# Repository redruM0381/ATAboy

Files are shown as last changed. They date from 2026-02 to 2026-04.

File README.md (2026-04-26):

If you don't want to build your own, the hardware can be purchased here:  https://obsoletetech.us/products/ataboy-an-open-source-legacy-ide-usb-bridge

-----------------------------------------------------------------------------------

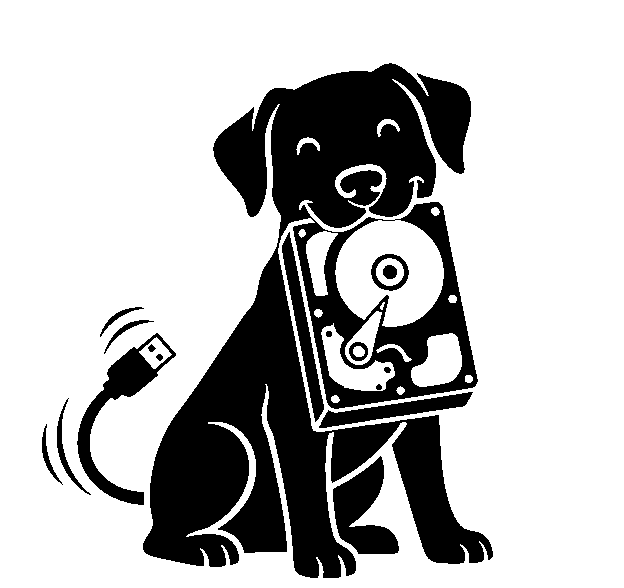
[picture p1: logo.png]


ATAboy is designed for retro computing enthusiasts, data recovery experts, and archivists.  Read and write the oldest of IDE hard drives, without the need for an "in-between" vintage computer!

ATAboy is a user-friendly bridge that allows classic IDE (PATA) hard drives to be connected to a modern computer over USB as a standard USB Mass Storage device.  While cheap, modern adapters usually only work with newer "LBA" type drives, ATAboy works all the way back to the earliest CHS only, PIO Mode 0, ATA disks.  (It will also work with newer LBA type IDE disks, but that's not really what it's designed for.)  ATAboy features an "Award BIOS inspired" user friendly UI for drive configuration and setup.

---

When connected:

* The IDE drive appears to your computer like a normal USB Mass Storage Device
* No special drivers are required (Windows, Linux, macOS supported)
* The device translates USB Mass Storage commands into IDE read/write operations

---

## Hardware Requirements

To get started, you will also need:

* Any 40‑pin IDE (PATA) hard drive. It may be jumpered master, slave, or cable select.
* An external PSU to power the drive.
* A USB-C cable to connect ATAboy to the host computer.
* Any standard ANSI compatible serial terminal emulator (e.g. PuTTY, Tera Term, minicom, screen, etc.)

---

## Basic drive mount using ATABoy

1. Connect the IDE ribbon cable to the drive and ATAboy (Note Pin 1 orientation, usually marked by a stripe on the cable)
2. Power the drive using external supply
3. Connect ATAboy to your computer via USB
4. Connect to serial console with terminal of choice ([PuTTY](https://www.chiark.greenend.org.uk/~sgtatham/putty/latest.html) shown).  9600 8N1, no flow control.  You should see an Award BIOS "inspired" text-based UI appear in the terminal.
5. Enter the "Auto Detect & Set Geometry" menu
6. Choose default, or enter geometry manually if needed
7. Choose "Mount HDD to USB Mass Storage"
8. That's it!  You can now read the drive from your modern OS!

---

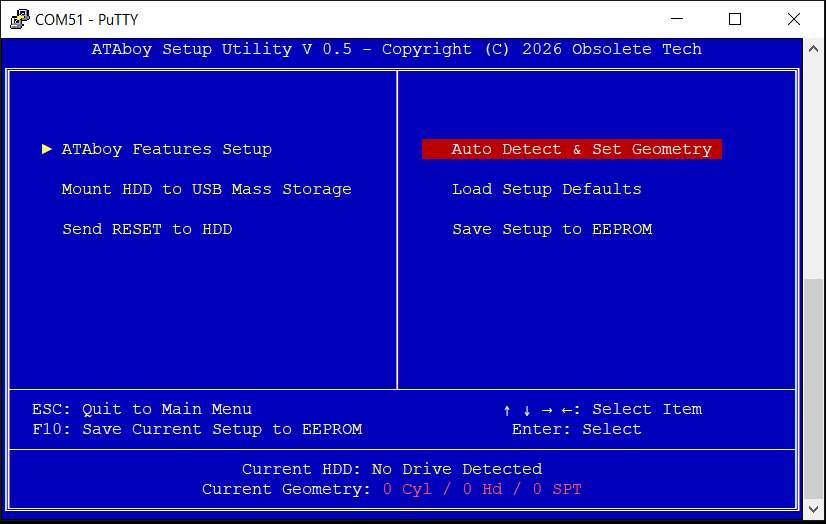
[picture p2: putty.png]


You can save the current ATAboy settings, geometry, etc to EEPROM, which will be restored the next time the device is booted.  (This allows auto-mounting also.)

IMPORTANT!  If you are working with valuable or irreplaceable data, ensure write protection is enabled before mounting.  It is enabled by default for safety.  You do NOT want the host OS to touch or bless the disk!
Windows VDS/RPC services can often crash if it is unable to write to a drive with damaged/legacy MBR and/or partition tables.
This can result in various Windows errors, unable to mount the drive, etc.  However, raw data can usually still be accessed via dd, or other raw disk backup software.
Regardless, it is STRONGLY recommended the entire drive be dumped to an image file BEFORE disabling write protection, then mounting the drive in Explorer.

---

## Safe Removal

Always use your operating system’s **Safely Remove / Eject** feature before:

* Unplugging the USB cable
* Powering off the IDE drive

This helps prevent:

* File system corruption
* Incomplete writes
* OS-side errors

---

## Known Limitations

ATAboy is a hobbyist and experimental project. You should be aware that:

* Performance is significantly slower than modern USB to IDE bridges.  We're working over USB 1.1 for now.  This can cause long mount times, especially in Windows if the disk has file system weirdness.
* Many legacy disks use unusual geometry, and may require experimentation.
* Not all OS disk utilities behave the same way

# PLEASE NOTE!
Some of the firmware code was written with AI assistance.  It has been tested with dozens of drives, and does function well with most.  But may be buggy, slow, or unresponsive with certain drives. Please let us know if you find a drive that does or doesn't work right. We'll build a compatibilty list soon.
# Use at your own risk!

* Firmware written in VS Code with Raspberry Pi Pico Extension
* PCB designed in Kicad
* Case designed in Freecad

---

ATAboy is meant to be hacked, learned from, and improved.
Have fun, and thank you for trying ATAboy!

# Licensing

"ATAboy" is a trademark of JJ Dasher.
The open source licenses do not grant rights to use these trademarks.

## Firmware
Licensed under GNU GPLv3.
See /firmware/LICENSE.

## Hardware
Licensed under CERN-OHL-W v2.
See /PCB/LICENSE.

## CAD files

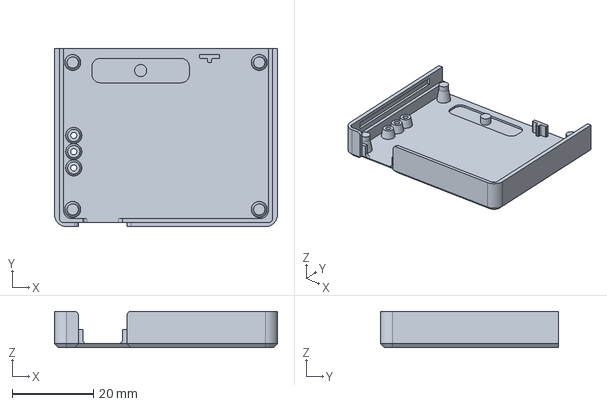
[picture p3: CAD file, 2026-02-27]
Case STLs/case_angled_shroud.FCStd
55.0 x 44.0 x 9.00 mm

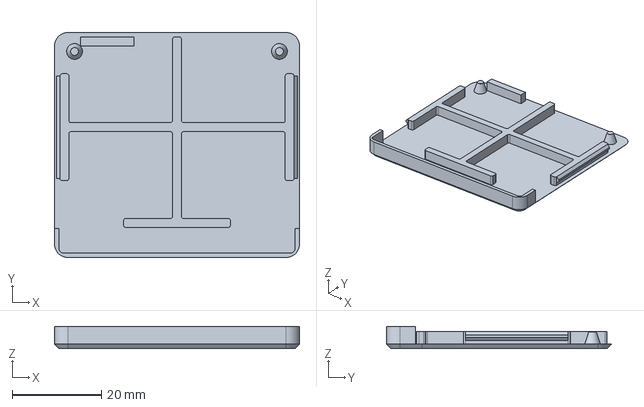
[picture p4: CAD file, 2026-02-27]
Case STLs/lid_angled_shroud.FCStd
55.0 x 50.5 x 5.00 mm

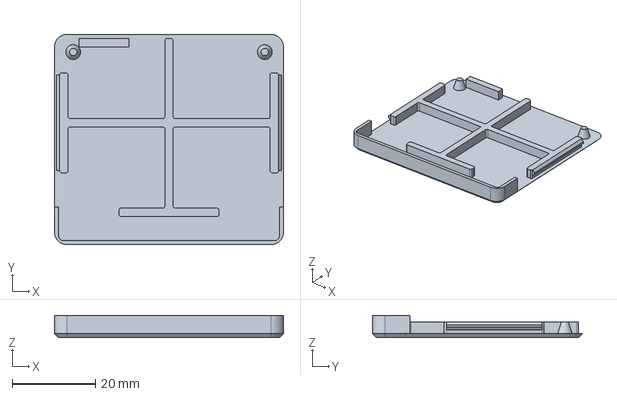
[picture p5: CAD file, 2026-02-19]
Case STLs/lid_vert_shroud.FCStd
55.0 x 50.5 x 5.40 mm

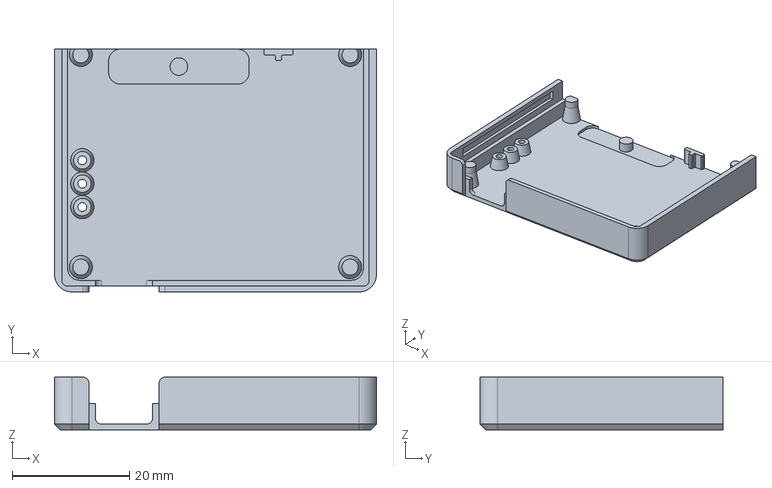
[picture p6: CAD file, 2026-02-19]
Case STLs/case_vert_shroud.FCStd
55.0 x 41.5 x 9.00 mm

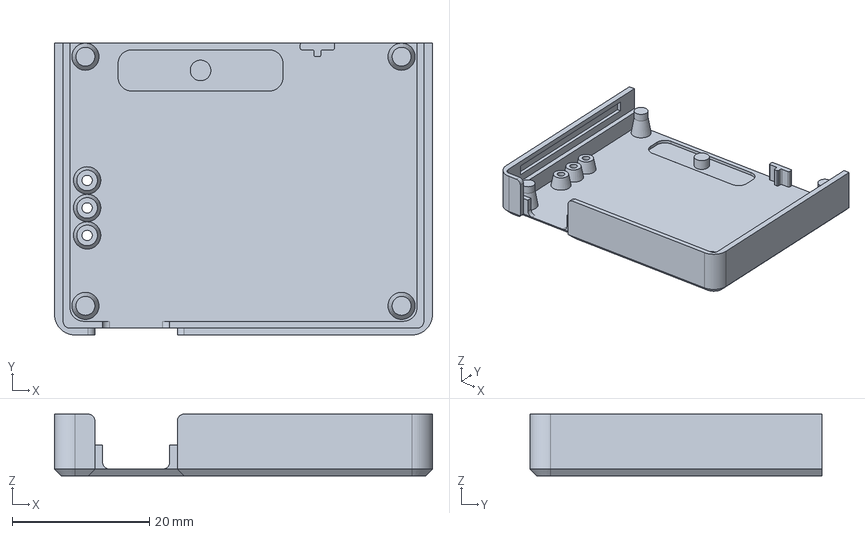
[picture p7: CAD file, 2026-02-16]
Case STLs/case_vert_header.FCStd
55.0 x 42.5 x 9.00 mm

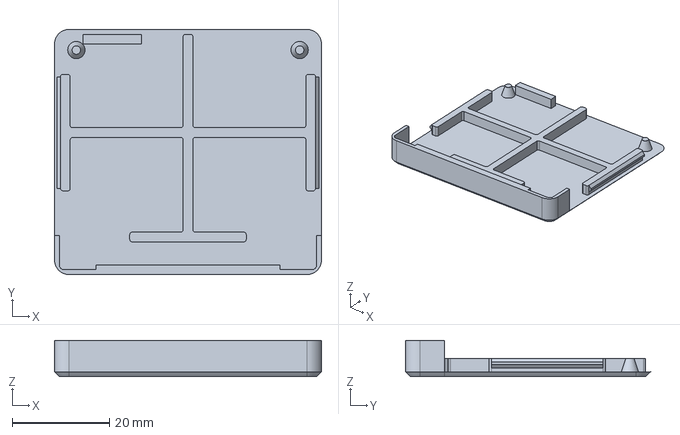
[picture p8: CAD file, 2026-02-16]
Case STLs/lid_vert_header.FCStd
55.0 x 50.5 x 7.50 mm

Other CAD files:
Case STLs/case_angled_shroud.stl
Case STLs/case_vert_header.stl
Case STLs/case_vert_shroud.stl
Case STLs/lid_angled_shroud.stl
Case STLs/lid_vert_header.stl
Case STLs/lid_vert_shroud.stl

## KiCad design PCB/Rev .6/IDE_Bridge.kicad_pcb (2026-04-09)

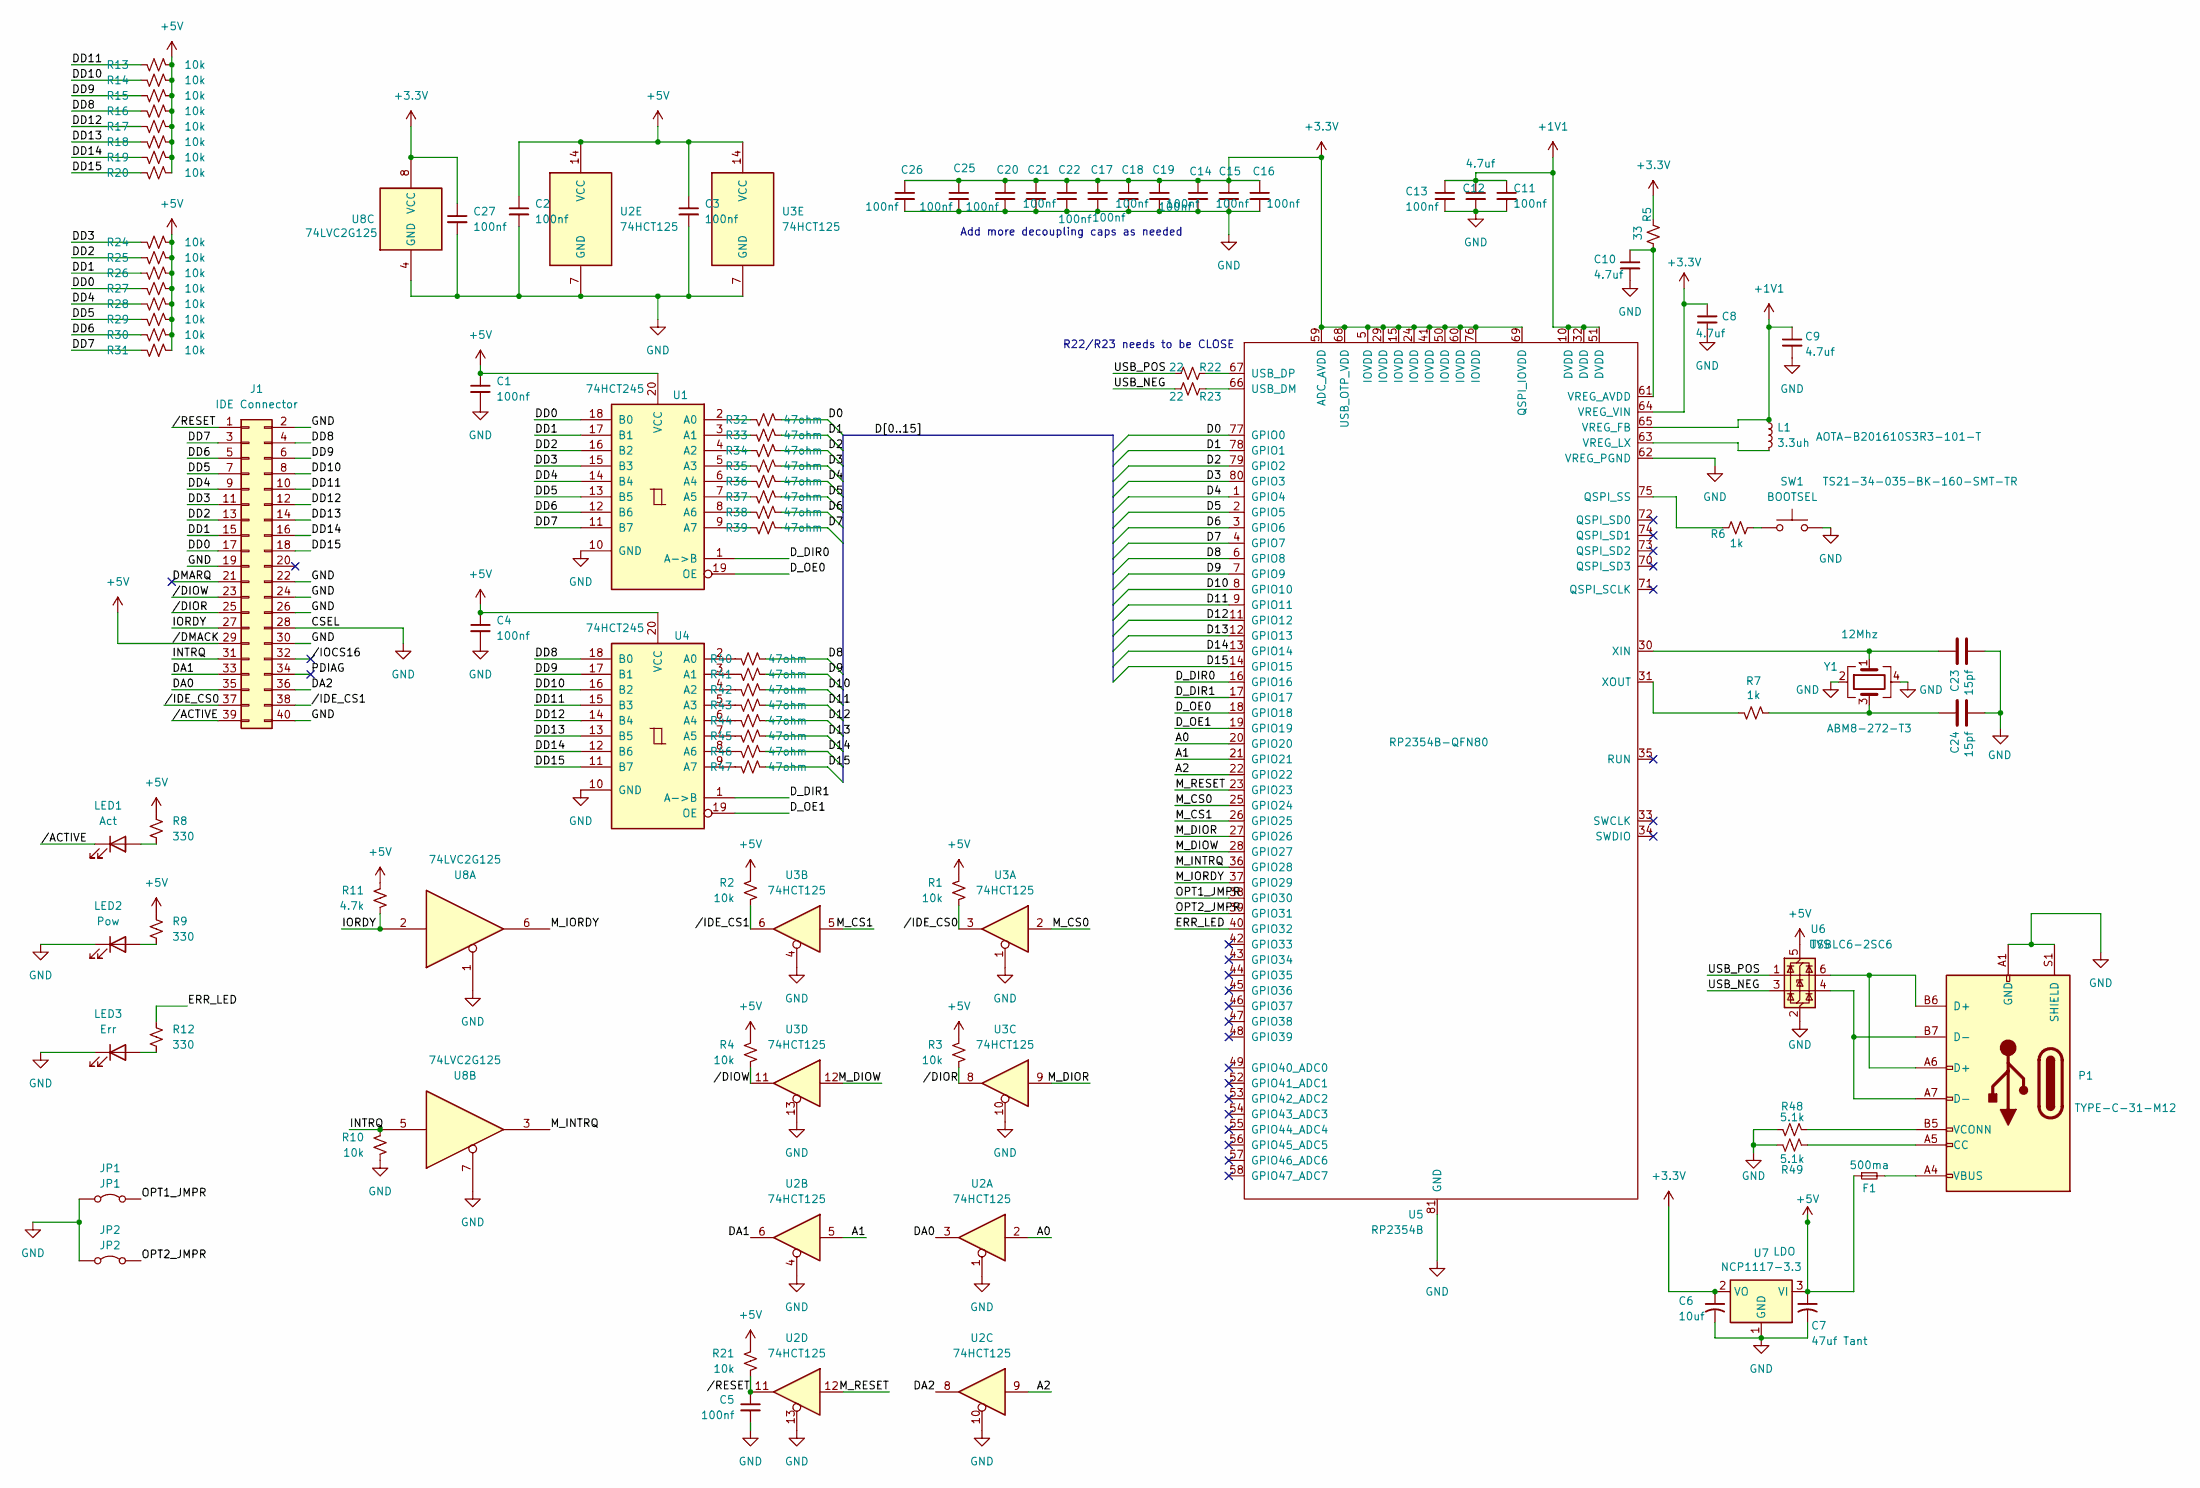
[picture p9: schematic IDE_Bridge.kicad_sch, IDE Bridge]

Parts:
C1, C2, C3, C4, C5, C11, C13, C14, C15, C16, C17, C18, C19, C20, C21, C22, C25, C26, C27: 100nf; C_0402_1005Metric; LCSC C1525
C6: 10uf; C_1206_3216Metric; LCSC C13585
C7: 47uf Tant; CP_EIA-6032-28_Kemet-C; LCSC C7219
C8, C9, C10, C12: 4.7uf; C_0402_1005Metric; LCSC C23733
C23, C24: 15pf; C_0402_1005Metric; LCSC C1548
F1: 500ma; Fuse_0805_2012Metric; LCSC C22435710
J1: IDE Connector; PinHeader_2x20_P2.54mm_Horizontal
JP1: JP1; PinHeader_1x02_P2.54mm_Vertical
JP2: JP2; PinHeader_1x02_P2.54mm_Vertical
L1: 3.3uh; L_Murata_DFE201610P; LCSC C42411119
LED1: Act; LED_0805_2012Metric; LCSC C2296
LED2: Pow; LED_0805_2012Metric; LCSC C2297
LED3: Err; LED_0805_2012Metric; LCSC C84256
P1: USB_C_Plug_USB2.0; USB_C_Receptacle_HRO_TYPE-C-31-M-12; LCSC C165948
R1, R2, R3, R4, R10, R13, R14, R15, R16, R17, R18, R19, R20, R21, R24, R25, R26, R27, R28, R29, R30, R31: 10k; R_0402_1005Metric; LCSC C25744
R5: 33; R_0402_1005Metric; LCSC C25105
R6, R7: 1k; R_0402_1005Metric; LCSC C11702
R8, R9, R12: 330; R_0402_1005Metric; LCSC C25104
R11: 4.7k; R_0402_1005Metric; LCSC C25900
R22, R23: 22; R_0402_1005Metric; LCSC C25092
R32, R33, R34, R35, R36, R37, R38, R39, R40, R41, R42, R43, R44, R45, R46, R47: 47ohm; R_0402_1005Metric; LCSC C25118
R48, R49: 5.1k; R_0402_1005Metric; LCSC C25905
SW1: BOOTSEL; SW_SPST_SKQG_WithStem; LCSC C318884
U1, U4: 74HCT245; SOIC-20W_7.5x12.8mm_P1.27mm; LCSC C5625
U2, U3: 74HCT125; SOIC-14_3.9x8.7mm_P1.27mm; LCSC C352957
U5: RP2354B; RP2350B; LCSC C39843328
U6: TVS; SOT-23-6; LCSC C2687116
U7: LDO; SOT-223-3_TabPin2; LCSC C6186
U8: 74LVC2G125; VSSOP-8_3x3mm_P0.65mm; LCSC C206035
Y1: 12Mhz; Crystal_SMD_3225-4Pin_3.2x2.5mm; LCSC C20625731

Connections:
+1V1: C9.1, C11.1, C12.1, C13.1, L1.1, U5.10 (DVDD), U5.32 (DVDD), U5.51 (DVDD), U5.65 (VREG_FB)
+3.3V: C6.1, C8.1, C14.1, C15.1, C16.1, C17.1, C18.1, C19.1, C20.1, C21.1, C22.1, C25.1, C26.1, C27.1, R5.2, U5.5 (IOVDD), U5.15 (IOVDD), U5.24 (IOVDD), U5.29 (IOVDD), U5.41 (IOVDD), U5.50 (IOVDD), U5.59 (ADC_AVDD), U5.60 (IOVDD), U5.64 (VREG_VIN), U5.68 (USB_OTP_VDD), U5.69 (QSPI_IOVDD), U5.76 (IOVDD), U7.2 (VO), U8.8 (VCC)
+5V: C1.1, C2.1, C3.1, C4.1, C7.1, F1.1, J1.29, R1.1, R2.1, R3.1, R4.1, R8.1, R9.1, R11.1, R13.2, R14.2, R15.2, R16.2, R17.2, R18.2, R19.2, R20.2, R21.1, R24.2, R25.2, R26.2, R27.2, R28.2, R29.2, R30.2, R31.2, U1.20 (VCC), U2.14 (VCC), U3.14 (VCC), U4.20 (VCC), U6.5 (VBUS), U7.3 (VI)
/A0: U2.2, U5.20 (GPIO20)
/A1: U2.5, U5.21 (GPIO21)
/A2: U2.9, U5.22 (GPIO22)
/D0: R32.2, U5.77 (GPIO0)
/D1: R33.2, U5.78 (GPIO1)
/D2: R34.2, U5.79 (GPIO2)
/D3: R35.2, U5.80 (GPIO3)
/D4: R36.2, U5.1 (GPIO4)
/D5: R37.2, U5.2 (GPIO5)
/D6: R38.2, U5.3 (GPIO6)
/D7: R39.2, U5.4 (GPIO7)
/D8: R40.2, U5.6 (GPIO8)
/D9: R41.2, U5.7 (GPIO9)
/D10: R42.2, U5.8 (GPIO10)
/D11: R43.2, U5.9 (GPIO11)
/D12: R44.2, U5.11 (GPIO12)
/D13: R45.2, U5.12 (GPIO13)
/D14: R46.2, U5.13 (GPIO14)
/D15: R47.2, U5.14 (GPIO15)
/DA0: J1.35, U2.3
/DA1: J1.33, U2.6
/DA2: J1.36, U2.8
/DD0: J1.17, R27.1, U1.18 (B0)
/DD1: J1.15, R26.1, U1.17 (B1)
/DD2: J1.13, R25.1, U1.16 (B2)
/DD3: J1.11, R24.1, U1.15 (B3)
/DD4: J1.9, R28.1, U1.14 (B4)
/DD5: J1.7, R29.1, U1.13 (B5)
/DD6: J1.5, R30.1, U1.12 (B6)
/DD7: J1.3, R31.1, U1.11 (B7)
/DD8: J1.4, R16.1, U4.18 (B0)
/DD9: J1.6, R15.1, U4.17 (B1)
/DD10: J1.8, R14.1, U4.16 (B2)
/DD11: J1.10, R13.1, U4.15 (B3)
/DD12: J1.12, R17.1, U4.14 (B4)
/DD13: J1.14, R18.1, U4.13 (B5)
/DD14: J1.16, R19.1, U4.12 (B6)
/DD15: J1.18, R20.1, U4.11 (B7)
/DMARQ: J1.21
/D_DIR0: U1.1 (A->B), U5.16 (GPIO16)
/D_DIR1: U4.1 (A->B), U5.17 (GPIO17)
/D_OE0: U1.19 (OE), U5.18 (GPIO18)
/D_OE1: U4.19 (OE), U5.19 (GPIO19)
/ERR_LED: R12.1, U5.40 (GPIO32)
/INTRQ: J1.31, R10.1, U8.5
/IORDY: J1.27, R11.2, U8.2
/M_CS0: U3.2, U5.25 (GPIO24)
/M_CS1: U3.5, U5.26 (GPIO25)
/M_DIOR: U3.9, U5.27 (GPIO26)
/M_DIOW: U3.12, U5.28 (GPIO27)
/M_INTRQ: U5.36 (GPIO28), U8.3
/M_IORDY: U5.37 (GPIO29), U8.6
/M_RESET: U2.12, U5.23 (GPIO23)
/OPT1_JMPR: JP1.2 (B), U5.38 (GPIO30)
/OPT2_JMPR: JP2.2 (B), U5.39 (GPIO31)
/PDIAG: J1.34
/USB_NEG: R23.1, U6.3 (I/O2)
/USB_POS: R22.1, U6.1 (I/O1)
//ACTIVE: J1.39, LED1.1 (K)
//DIOR: J1.25, R3.2, U3.8
//DIOW: J1.23, R4.2, U3.11
//IDE_CS0: J1.37, R1.2, U3.3
//IDE_CS1: J1.38, R2.2, U3.6
//IOCS16: J1.32
//RESET: C5.1, J1.1, R21.2, U2.11
GND: C1.2, C2.2, C3.2, C4.2, C5.2, C6.2, C7.2, C8.2, C9.2, C10.2, C11.2, C12.2, C13.2, C14.2, C15.2, C16.2, C17.2, C18.2, C19.2, C20.2, C21.2, C22.2, C23.2, C24.2, C25.2, C26.2, C27.2, J1.2, J1.19, J1.22, J1.24, J1.26, J1.28, J1.30, J1.40, JP1.1 (A), JP2.1 (A), LED2.1 (K), LED3.1 (K), P1.A1 (GND), P1.A12 (GND), P1.B1 (GND), P1.B12 (GND), P1.S1 (SHIELD), R10.2, R48.1, R49.1, SW1.2, U1.10 (GND), U2.1, U2.4, U2.7 (GND), U2.10, U2.13, U3.1, U3.4, U3.7 (GND), U3.10, U3.13, U4.10 (GND), U5.62 (VREG_PGND), U5.81 (GND), U6.2 (GND), U7.1 (GND), U8.1, U8.4 (GND), U8.7, Y1.2, Y1.4
unnamed: C24.1, R7.2, Y1.3
unnamed: F1.2, P1.A4 (VBUS), P1.A9 (VBUS), P1.B4 (VBUS), P1.B9 (VBUS)
unnamed: LED1.2 (A), R8.2
unnamed: LED2.2 (A), R9.2
unnamed: LED3.2 (A), R12.2
unnamed: P1.A5 (CC), R49.2
unnamed: P1.A6 (D+), P1.B6 (D+), U6.6 (I/O1)
unnamed: P1.A7 (D-), P1.B7 (D-), U6.4 (I/O2)
unnamed: P1.B5 (VCONN), R48.2
unnamed: R6.1, SW1.1
unnamed: R32.1, U1.2 (A0)
unnamed: R33.1, U1.3 (A1)
unnamed: R34.1, U1.4 (A2)
unnamed: R35.1, U1.5 (A3)
unnamed: R36.1, U1.6 (A4)
unnamed: R37.1, U1.7 (A5)
unnamed: R38.1, U1.8 (A6)
unnamed: R39.1, U1.9 (A7)
unnamed: R40.1, U4.2 (A0)
unnamed: R41.1, U4.3 (A1)
unnamed: R42.1, U4.4 (A2)
unnamed: R43.1, U4.5 (A3)
unnamed: R44.1, U4.6 (A4)
unnamed: R45.1, U4.7 (A5)
unnamed: R46.1, U4.8 (A6)
unnamed: R47.1, U4.9 (A7)
unnamed: R6.2, U5.75 (QSPI_SS)
unnamed: R23.2, U5.66 (USB_DM)
unnamed: R22.2, U5.67 (USB_DP)
unnamed: C10.1, R5.1, U5.61 (VREG_AVDD)
unnamed: L1.2, U5.63 (VREG_LX)
unnamed: C23.1, U5.30 (XIN), Y1.1
unnamed: R7.1, U5.31 (XOUT)

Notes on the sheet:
Add more decoupling caps as needed
R22/R23 needs to be CLOSE

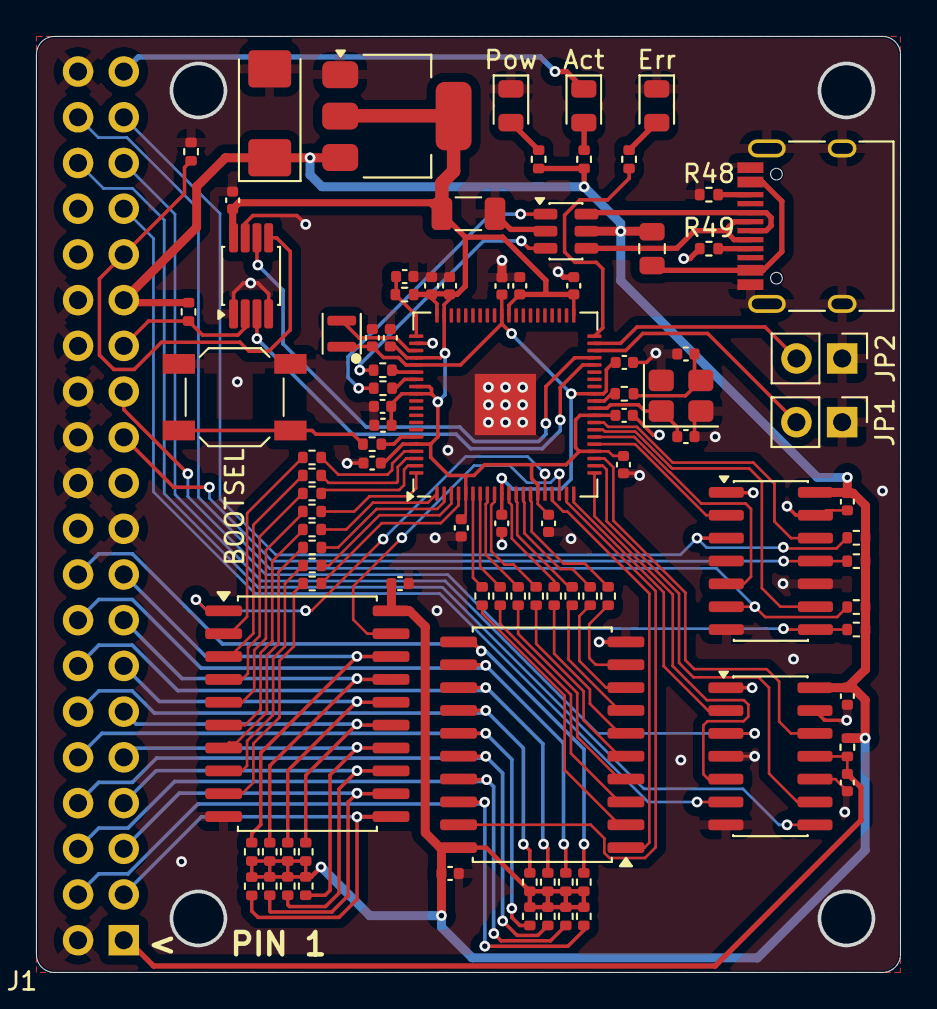
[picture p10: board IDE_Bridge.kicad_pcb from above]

Board: 2 copper layers, 48.0 x 52.0 mm, 95 parts (0 on the bottom side), 99 nets.

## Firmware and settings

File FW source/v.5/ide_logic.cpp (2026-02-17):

//
// ATAboy Firmware
// Copyright (c) 2026 JJ Dasher
//
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
// See the LICENSE file in this directory for details.
//


#include "ide_logic.h" 
#include "pico/stdlib.h"
#include "hardware/gpio.h"
#include "hardware/structs/sio.h"
#include "hardware/sync.h"
#include "tusb.h"
#include "pico/time.h"
#include <string.h>

// Immediate mitigation: prevent TinyUSB re-entry from IDE I/O paths.
// Replace calls to tud_task() in this file with TUSB_POLL_SAFE(), which
// yields without re-entering TinyUSB.  This will pause USB/CDC briefly
// during IDE ops but avoids reentrancy crashes.
#ifndef TUSB_POLL_SAFE
#define TUSB_POLL_SAFE() tight_loop_contents()
#endif

// Map board_millis to the Pico SDK equivalent
#define board_millis() to_ms_since_boot(get_absolute_time())
#define IDE_REG_STATUS 7

extern "C" {

// Access the global flag from menus.c
extern bool comp_timings;

// --- Simple read cache ---
#ifndef READ_CACHE_SECTORS
#define READ_CACHE_SECTORS 128
#endif

static uint8_t read_cache_buf[READ_CACHE_SECTORS * 512];
static uint64_t read_cache_start = 0xFFFFFFFFFFFFFFFF;
static uint32_t read_cache_count = 0;

/* ================= SHARED GLOBALS ================= */
uint8_t  drive_heads = 0;
uint8_t  drive_spt = 0;
uint16_t drive_cylinders = 0; 
bool     is_mounted = false; 
bool     drive_write_protected = true;
bool    use_lba_mode = false;
bool    drive_supports_lba48 = false;
extern uint64_t total_lba_sectors_from_identify; 
extern uint16_t cur_cyls;
extern uint8_t  cur_heads;
extern uint8_t  cur_spt;

// Forward decls for helpers
static inline void ide_setup_lba48(uint64_t lba, uint16_t count);
static inline void ide_setup_lba28(uint32_t lba, uint8_t count);

/* ================= PIN DEFINITIONS ================= */
#define DATA_MASK   0x0000FFFF 
#define IDE_CS0     24
#define IDE_CS1     25   
#define IDE_DIOR    26
#define IDE_DIOW    27
#define IDE_RESET   23
#define IDE_A0      20
#define IDE_A1      21
#define IDE_A2      22
#define ADDR_MASK   ((1 << IDE_A0) | (1 << IDE_A1) | (1 << IDE_A2))
#define IDE_DIR     16 
#define IDE_DIR1    17
#define IDE_OE      18
#define IDE_OE1     19
#define CTRL_MASK   ((1 << IDE_CS0) | (1 << IDE_CS1) | (1 << IDE_DIOR) | (1 << IDE_DIOW))

/* ================= BUS LOGIC HELPERS ================= */

void ide_flush_cache() {
    read_cache_start = 0xFFFFFFFFFFFFFFFF;
    read_cache_count = 0;
}

void bus_idle() {
    sio_hw->gpio_set = (1 << IDE_CS0) | (1 << IDE_CS1) | (1 << IDE_DIOR) | (1 << IDE_DIOW);
    sio_hw->gpio_clr = (1 << IDE_DIR) | (1 << IDE_DIR1); // In
    sio_hw->gpio_set = (1 << IDE_OE) | (1 << IDE_OE1);   // Disable
    sio_hw->gpio_oe_clr = DATA_MASK; 
}

void set_address(uint8_t addr) {
    uint32_t addr_val = (uint32_t)(addr & 0x07) << IDE_A0;
    sio_hw->gpio_clr = ADDR_MASK;
    sio_hw->gpio_set = addr_val;
}

void data_mode_in() {
    sio_hw->gpio_set = (1 << IDE_OE) | (1 << IDE_OE1); 
    sio_hw->gpio_oe_clr = DATA_MASK;
    sio_hw->gpio_clr = (1 << IDE_DIR) | (1 << IDE_DIR1);
    busy_wait_at_least_cycles(20); 
    sio_hw->gpio_clr = (1 << IDE_OE) | (1 << IDE_OE1);
}

// NOTE: We will use separate data_mode_out timings inline for compat vs fast
void data_mode_out_fast(uint16_t val) {
    sio_hw->gpio_set = (1 << IDE_OE) | (1 << IDE_OE1);
    sio_hw->gpio_out = (sio_hw->gpio_out & ~DATA_MASK) | ((uint32_t)val & DATA_MASK);
    sio_hw->gpio_oe_set = DATA_MASK;
    sio_hw->gpio_set = (1 << IDE_DIR) | (1 << IDE_DIR1);
    busy_wait_at_least_cycles(100); 
    sio_hw->gpio_clr = (1 << IDE_OE) | (1 << IDE_OE1);
}

void data_mode_out_compat(uint16_t val) {
    sio_hw->gpio_set = (1 << IDE_OE) | (1 << IDE_OE1);
    sio_hw->gpio_out = (sio_hw->gpio_out & ~DATA_MASK) | ((uint32_t)val & DATA_MASK);
    sio_hw->gpio_oe_set = DATA_MASK;
    sio_hw->gpio_set = (1 << IDE_DIR) | (1 << IDE_DIR1);
    busy_wait_at_least_cycles(400); // Increased buffer setup
    sio_hw->gpio_clr = (1 << IDE_OE) | (1 << IDE_OE1);
}

void lba_to_chs(uint32_t lba, uint16_t* c, uint8_t* h, uint8_t* s) {
    *s = (lba % drive_spt) + 1;
    uint32_t temp = lba / drive_spt;
    *h = temp % drive_heads;
    *c = temp / drive_heads;
}

/* ================= LOW LEVEL REGISTER I/O (DUPLICATED) ================= */




// --- FAST VERSIONS (Original Timings) ---
uint8_t ide_read_8_fast(uint8_t reg) {
    set_address(reg);
    sio_hw->gpio_set = (1 << IDE_DIOR) | (1 << IDE_DIOW); 
    data_mode_in();
    sio_hw->gpio_clr = (1 << IDE_CS0);
    busy_wait_at_least_cycles(20);
    sio_hw->gpio_clr = (1 << IDE_DIOR);
    busy_wait_at_least_cycles(400); 
    uint8_t val = (uint8_t)(sio_hw->gpio_in & 0xFF);
    sio_hw->gpio_set = (1 << IDE_DIOR) | (1 << IDE_CS0);
    bus_idle();
    return val;
}

void ide_write_8_fast(uint8_t reg, uint8_t val) {
    set_address(reg);
    data_mode_out_fast(val);
    sio_hw->gpio_clr = (1 << IDE_CS0);
    busy_wait_at_least_cycles(10);
    sio_hw->gpio_clr = (1 << IDE_DIOW);    
    busy_wait_at_least_cycles(200); 
    sio_hw->gpio_set = (1 << IDE_DIOW) | (1 << IDE_CS0);
    bus_idle();
    busy_wait_at_least_cycles(200);
}

uint16_t ide_read_16_fast(uint8_t reg) {
    set_address(reg);
    sio_hw->gpio_set = (1 << IDE_DIOR) | (1 << IDE_DIOW);
    data_mode_in();
    sio_hw->gpio_clr = (1 << IDE_CS0);
    busy_wait_at_least_cycles(50);
    sio_hw->gpio_clr = (1 << IDE_DIOR);
    busy_wait_at_least_cycles(500);
    uint16_t val = (uint16_t)(sio_hw->gpio_in & DATA_MASK);
    sio_hw->gpio_set = (1 << IDE_DIOR);
    busy_wait_at_least_cycles(500);
    sio_hw->gpio_set = (1 << IDE_CS0);
    bus_idle();
    return val;
}

// --- COMPAT VERSIONS (Relaxed Timings) ---
uint8_t ide_read_8_compat(uint8_t reg) {
    set_address(reg);
    sio_hw->gpio_set = (1 << IDE_DIOR) | (1 << IDE_DIOW); 
    data_mode_in();
    sio_hw->gpio_clr = (1 << IDE_CS0);
    busy_wait_at_least_cycles(150); // Setup increased
    sio_hw->gpio_clr = (1 << IDE_DIOR);
    busy_wait_at_least_cycles(1200); // Pulse increased significantly
    uint8_t val = (uint8_t)(sio_hw->gpio_in & 0xFF);
    sio_hw->gpio_set = (1 << IDE_DIOR) | (1 << IDE_CS0);
    bus_idle();
    return val;
}

void ide_write_8_compat(uint8_t reg, uint8_t val) {
    set_address(reg);
    data_mode_out_compat(val); // Uses relaxed data_mode_out
    sio_hw->gpio_clr = (1 << IDE_CS0);
    busy_wait_at_least_cycles(150);
    sio_hw->gpio_clr = (1 << IDE_DIOW);    
    busy_wait_at_least_cycles(1200); // Pulse increased
    sio_hw->gpio_set = (1 << IDE_DIOW) | (1 << IDE_CS0);
    bus_idle();
    busy_wait_at_least_cycles(1200); // Recovery increased
}
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

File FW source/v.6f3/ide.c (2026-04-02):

#include "ide.h"
#include "ide_pio.h"
#include "config.h"
#include "hardware/gpio.h"
#include "hardware/structs/sio.h"
#include "pico/stdlib.h"
#include "pico/time.h"

static uint8_t dev_base = 0xA0;   // 0xA0 = master, 0xB0 = slave

void ide_select_device(uint8_t base) { dev_base = base; }

// ---------------------------------------------------------------------------
//  Bus helpers — address, transceiver, and chip-select (all SIO-managed)
// ---------------------------------------------------------------------------

static void bus_idle(void) {
    sio_hw->gpio_set = (1 << IDE_CS0) | (1 << IDE_CS1);
    sio_hw->gpio_clr = (1 << IDE_DIR) | (1 << IDE_DIR1);   // DIR = read
    sio_hw->gpio_set = (1 << IDE_OE) | (1 << IDE_OE1);     // OE disabled
}

static void set_address(uint8_t addr) {
    sio_hw->gpio_clr = ADDR_MASK;
    sio_hw->gpio_set = (uint32_t)(addr & 0x07) << IDE_A0;
}

static void xcvr_read(void) {
    sio_hw->gpio_set = (1 << IDE_OE) | (1 << IDE_OE1);     // disable first
    sio_hw->gpio_clr = (1 << IDE_DIR) | (1 << IDE_DIR1);   // DIR = IDE -> Pico
    busy_wait_at_least_cycles(20);                            // 74HCT245 switch time
    sio_hw->gpio_clr = (1 << IDE_OE) | (1 << IDE_OE1);     // enable
}

static void xcvr_write(void) {
    sio_hw->gpio_set = (1 << IDE_OE) | (1 << IDE_OE1);     // disable first
    sio_hw->gpio_set = (1 << IDE_DIR) | (1 << IDE_DIR1);   // DIR = Pico -> IDE
    busy_wait_at_least_cycles(20);
    sio_hw->gpio_clr = (1 << IDE_OE) | (1 << IDE_OE1);     // enable
}

// ---------------------------------------------------------------------------
//  Register I/O — single 8-bit reads/writes via PIO strobes
// ---------------------------------------------------------------------------

void ide_write_reg(uint8_t reg, uint8_t val) {
    set_address(reg);
    xcvr_write();
    sio_hw->gpio_clr = (1 << IDE_CS0);

    uint16_t word = (uint16_t)val;
    ide_pio_write(1, &word);

    sio_hw->gpio_set = (1 << IDE_CS0);
    bus_idle();
}

uint8_t ide_read_reg(uint8_t reg) {
    set_address(reg);
    xcvr_read();
    sio_hw->gpio_clr = (1 << IDE_CS0);

    uint16_t val;
    ide_pio_read(1, &val);

    sio_hw->gpio_set = (1 << IDE_CS0);
    bus_idle();
    return (uint8_t)(val & 0xFF);
}

uint8_t ide_read_alt_status(void) {
    set_address(6);
    xcvr_read();
    sio_hw->gpio_clr = (1 << IDE_CS1);

    uint16_t val;
    ide_pio_read(1, &val);

    sio_hw->gpio_set = (1 << IDE_CS1);
    bus_idle();
    return (uint8_t)(val & 0xFF);
}

void ide_write_control(uint8_t val) {
    set_address(6);
    xcvr_write();
    sio_hw->gpio_clr = (1 << IDE_CS1);

    uint16_t word = (uint16_t)val;
    ide_pio_write(1, &word);

    sio_hw->gpio_set = (1 << IDE_CS1);
    bus_idle();
}

void ide_set_iordy(bool enabled) {
    gpio_set_inover(IDE_IORDY, enabled ? GPIO_OVERRIDE_NORMAL : GPIO_OVERRIDE_HIGH);
}

// ---------------------------------------------------------------------------
//  Init / Reset / Polling
// ---------------------------------------------------------------------------

void ide_hw_init(void) {
    // SIO-controlled output pins
    uint32_t sio_out = (1 << IDE_DIR) | (1 << IDE_DIR1) |
                       (1 << IDE_OE)  | (1 << IDE_OE1)  |
                       ADDR_MASK |
                       (1 << IDE_RESET) |
                       (1 << IDE_CS0) | (1 << IDE_CS1);

    gpio_init_mask(sio_out);
    gpio_set_dir_out_masked(sio_out);

    // INTRQ — active-high from drive, idle low
    gpio_init(IDE_INTRQ);
    gpio_set_dir(IDE_INTRQ, GPIO_IN);
    gpio_pull_down(IDE_INTRQ);

    // IORDY — active-high when ready, pulled up as fallback
    gpio_init(IDE_IORDY);
    gpio_set_dir(IDE_IORDY, GPIO_IN);
    gpio_pull_up(IDE_IORDY);
    // Force IORDY HIGH so PIO wait instructions never block during init
    gpio_set_inover(IDE_IORDY, GPIO_OVERRIDE_HIGH);

    // Data bus pads: no pulls (PIO owns these pins after ide_pio_init)
    for (int i = 0; i < 16; i++) gpio_disable_pulls(i);

    // Bring up PIO state machines
    ide_pio_init();

    gpio_put(IDE_RESET, 1);
    bus_idle();

    // nIEN=0: allow INTRQ from the drive
    ide_write_control(0x00);

    // Restore IORDY based on config (override was HIGH for safe init)
    ide_set_iordy(config.iordy_enabled);
}

void ide_reset_drive(void) {
    // Force IORDY HIGH during reset — drive holds it LOW during POST
    ide_set_iordy(false);

    gpio_put(IDE_RESET, 0);
    sleep_ms(50);
    gpio_put(IDE_RESET, 1);
    sleep_ms(100);
    ide_write_control(0x00);
    ide_wait_until_ready(10000);

    // Recalibrate — seek heads to track 0 (required by some pre-ATA drives)
    ide_write_reg(6, dev_base);
    ide_write_reg(7, 0x10);
    ide_wait_until_ready(10000);

    // Restore IORDY to config setting — drive is ready for normal operation
    ide_set_iordy(config.iordy_enabled);
}

uint8_t ide_probe_devices(void) {
    ide_set_iordy(false);

    // Single hardware reset — both devices see it
    gpio_put(IDE_RESET, 0);
    sleep_ms(50);
    gpio_put(IDE_RESET, 1);
    sleep_ms(2000);           // generous POST delay (not status-based)
    ide_write_control(0x00);  // nIEN=0

    static const uint8_t addrs[] = {0xA0, 0xB0};
    for (int i = 0; i < 2; i++) {
        ide_write_reg(6, addrs[i]);       // select device
        busy_wait_us_32(50);              // let selection settle

        // Floating bus filter: 0xFF means no device (bus floats high)
        uint8_t st = ide_read_reg(7);
        if (st == 0xFF) continue;

        // Device present — wait for BSY to clear (not DRDY; some older
        // drives won't assert DRDY until after INITIALIZE DRIVE PARAMETERS)
        dev_base = addrs[i];
        uint32_t start = to_ms_since_boot(get_absolute_time());
        bool bsy_clear = false;
        while (to_ms_since_boot(get_absolute_time()) - start < 10000) {
            st = ide_read_reg(7);
            if (!(st & 0x80)) { bsy_clear = true; break; }
            busy_wait_us_32(10);
        }
        if (!bsy_clear) continue;

        // Recalibrate (required by some pre-ATA drives)
        ide_write_reg(6, addrs[i]);
        ide_write_reg(7, 0x10);
        ide_wait_until_ready(10000);

        ide_set_iordy(config.iordy_enabled);
        return addrs[i];
    }

    ide_set_iordy(config.iordy_enabled);
    return 0;  // no device found
}

bool ide_wait_until_ready(uint32_t timeout_ms) {
    uint32_t start = to_ms_since_boot(get_absolute_time());
    while (to_ms_since_boot(get_absolute_time()) - start < timeout_ms) {
        uint8_t st = ide_read_reg(7);
        if (!(st & 0x80) && (st & 0x40)) return true;   // BSY=0, DRDY=1
        busy_wait_us_32(10);
    }
    return false;
}

bool ide_set_geometry(uint8_t heads, uint8_t spt) {
    ide_write_reg(6, dev_base | ((heads - 1) & 0x0F));
    ide_write_reg(2, spt);
    ide_write_reg(7, 0x91);
    return ide_wait_until_ready(1000);
}
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

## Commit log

2026-01-09 Delete PCB/files.txt
    no need
2026-01-12 Add files via upload
    Lots of bug fixes
    [ide_logic.cpp]
2026-01-31 Delete bugged directory
    Cleaning up
    [ide_logic.cpp]
2026-01-31 Delete PCB directory
    Noit ready to share yet
    [IDE_Bridge.kicad_pcb, IDE_Bridge.kicad_sch]
2026-02-19 Rename ataboy lid vert shroud.stl to lid_vert_shroud.stl
    [lid_vert_shroud.stl]
2026-02-19 Rename ataboy lid vert shroud.FCStd to lid_vert_shroud.FCStd
    [lid_vert_shroud.FCStd]
2026-02-19 Rename ataboy case vert shroud.stl to case_vert_shroud.stl
    [case_vert_shroud.stl]
2026-02-19 Rename ataboy case vert shroud.FCStd to case_vert_shroud.FCStd
    [case_vert_shroud.FCStd]
2026-02-27 Rename ataboy lid angle shroud.stl to lid_angled_shroud.stl
    [lid_angled_shroud.stl]
2026-02-27 Rename ataboy lid angle shroud.FCStd to lid_angled_shroud.FCStd
    [lid_angled_shroud.FCStd]
2026-02-27 Rename ataboy case angle shroud.stl to case_angled_shroud.stl
    [case_angled_shroud.stl]
2026-02-27 Rename ataboy case angle shroud.FCStd to case_angled_shroud.FCStd
    [case_angled_shroud.FCStd]
2026-04-02 A slew of fixes and new features
    Ver .6f2 (changes since .6d1)
    Fixed erroneously swapped IORDY/INTRQ GPIOs.
    Now sends 10h recalibrate during reset.
    91h is re-asserted If drive self resets due to UNC or other error, so we can attempt retry.
    Now scans master/slave, and works regardless of jumpering.
    If register responds, but IDENTIFY fails, allows user to force geometry and continue anyway.
    And much more!
    [ide.c, ide_pio.c]
2026-04-02 LBA48 bug fix
    LBA48 had a bug. Disks over 132GB should work now.
    [ide.c, ide_pio.c]
2026-04-08 Updated PCB
    Rev .6 of PCB: FIxed USB-C connector position, and added 5.1k pulldowns for CC1/CC2
    [IDE_Bridge.kicad_pcb, IDE_Bridge.kicad_sch]
2026-04-08 Update PCB
    Rev .6 fixes USB-C connector placement, and adds 2x 5.1k pulldowns for CC lines.
    [IDE_Bridge.kicad_pcb, IDE_Bridge.kicad_sch]

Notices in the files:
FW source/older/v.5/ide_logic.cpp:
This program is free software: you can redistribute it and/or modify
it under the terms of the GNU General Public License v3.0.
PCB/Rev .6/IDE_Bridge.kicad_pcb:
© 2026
